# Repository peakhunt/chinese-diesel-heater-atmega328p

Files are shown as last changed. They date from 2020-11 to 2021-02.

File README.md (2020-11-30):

# DANGEROUS
please don't use it if you don't know what you are doing.  
this is still a work in progress and I'm just using it  
as an emergency for my personal heating in my workshop  
so that I can have a warm winter at least.  
  
some documents will be posted here later for those brave souls interested in this.

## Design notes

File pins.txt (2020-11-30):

LED                                                   Used
  PB5                                                 PB1,PB2,PB3,PB4,PB5
                                                      PC0,PC1,PC2,PC3,PC4,PC5
PWM                                                   PD0,PD1,PD2,PD3
  PB1
  PB2                                                 Availabl
                                                      PB0, PC6
GPIO Out
  PD2
  PD3
  PD4

GPIO In
  PD5
  PD6
  PD7

ADC
  PC0
  PC1
  PC2
  PC3

I2C
  PC4
  PC5

SPI
  PB3
  PB4
  PB5
  XXX - CS

UART
  PD0
  PD1

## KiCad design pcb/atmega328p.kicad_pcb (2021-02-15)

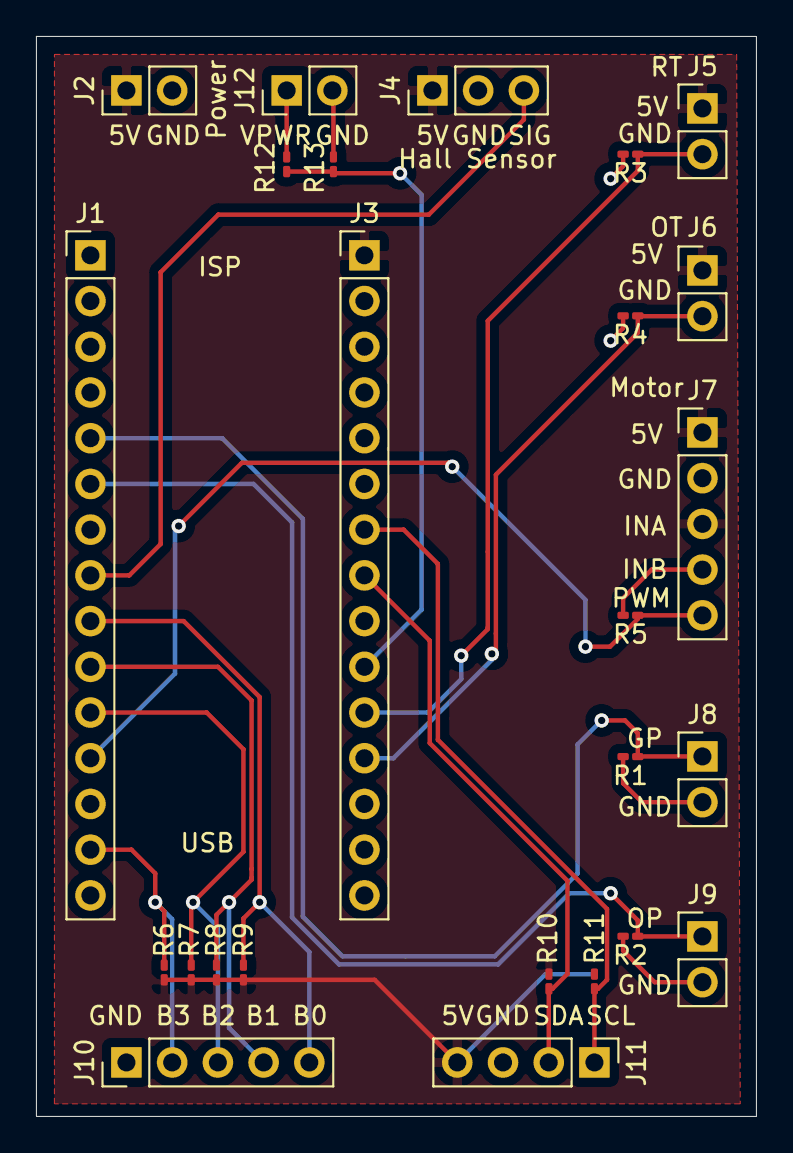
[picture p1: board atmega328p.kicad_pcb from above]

Board: 2 copper layers, 40.0 x 60.0 mm, 25 parts (0 on the bottom side), 16 nets.

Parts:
J1: Arduini MINI Left; PinHeader_1x15_P2.54mm_Vertical
J2, J12: Power; PinHeader_1x02_P2.54mm_Vertical
J3: Arduini MINI Right; PinHeader_1x15_P2.54mm_Vertical
J4: Hall Sensor; PinHeader_1x03_P2.54mm_Vertical
J5: Room Temperature; PinHeader_1x02_P2.54mm_Vertical
J6: Outlet Temperature; PinHeader_1x02_P2.54mm_Vertical
J7: Motor; PinHeader_1x05_P2.54mm_Vertical
J8: Glow Plug; PinHeader_1x02_P2.54mm_Vertical
J9: Oil Pump; PinHeader_1x02_P2.54mm_Vertical
J10: Buttons; PinHeader_1x05_P2.54mm_Vertical
J11: I2C; PinHeader_1x04_P2.54mm_Vertical
R1, R2, R5, R6, R7, R8, R9: 2K; R_0201_0603Metric_Pad0.64x0.40mm_HandSolder
R3, R4: 51K; R_0201_0603Metric_Pad0.64x0.40mm_HandSolder
R10, R11: 1K; R_0201_0603Metric_Pad0.64x0.40mm_HandSolder
R12: 6.8K; R_0201_0603Metric_Pad0.64x0.40mm_HandSolder
R13: 3.3K; R_0201_0603Metric_Pad0.64x0.40mm_HandSolder

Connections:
/5V: J2.1, J3.1, J4.1, J5.1, J6.1, J7.1, J7.3, J11.4, R6.2, R7.2, R8.2, R9.2, R10.1, R11.1
/12V: J12.1, R12.1
/BTN0: J1.9, J10.5, R9.1
/BTN1: J1.10, J10.4, R8.1
/BTN2: J1.11, J10.3, R7.1
/BTN3: J1.14, J10.2, R6.1
/GP_SIG: J1.5, J8.1, R1.1
/HS_INPUT: J1.8, J4.3
/M_PWM: J1.12, J7.5, R5.1
/OP_SIG: J1.6, J9.1, R2.1
/OT: J3.12, J6.2, R4.1
/RT: J3.11, J5.2, R3.1
/SCL: J3.7, J11.1, R11.2
/SDA: J3.8, J11.2, R10.2
/VPWR: J3.10, R12.2, R13.1
GND: J2.2, J3.2, J4.2, J7.2, J7.4, J8.2, J9.2, J10.1, J11.3, J12.2, R1.2, R2.2, R3.2, R4.2, R5.2, R13.2

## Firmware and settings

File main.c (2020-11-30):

#include <avr/io.h>
#include <avr/interrupt.h>

#include "mainloop_timer.h"
#include "event_dispatcher.h"
#include "sys_timer.h"
#include "misc.h"
#include "shell.h"
#include "pwm.h"
#include "gpio.h"
#include "adc_reader.h"

#include "heater.h"

int
main(void)
{
  // just to make sure, disable interrupt
  cli();

  event_dispatcher_init();
  mainloop_timer_init();

  pwm_init();
  gpio_init();
  misc_init();
  shell_init();
  sys_timer_init();

  adc_reader_init();

  heater_init();

  sei();

  shell_start();

  while(1)
  {
    event_dispatcher_dispatch();
  }
  return 0;
}

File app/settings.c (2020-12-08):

#include <avr/eeprom.h>
#include "settings.h"
#include "heater.h"
#include "glow_plug.h"
#include "oil_pump.h"

#define SETTINGS_MAGIC          0x1122334f
#define SETTINGS_EEPROM_ADDRESS 128

static settings_t   _settings;

void
settings_init(void)
{
  eeprom_read_block((void*)&_settings, (const void*)SETTINGS_EEPROM_ADDRESS, sizeof(settings_t));

  if(_settings.magic != SETTINGS_MAGIC)
  {
    // invalid settings
    // reset everything to default
    settings_reset();
  }
}

void
settings_reset(void)
{
  _settings.magic                             = SETTINGS_MAGIC;
  _settings.glow_plug_on_duration_for_start   = HEATER_HEATING_GLOW_PLUG_BEFORE_OIL_PUMP_PRIMING;
  _settings.oil_pump_priming_duration         = HEATER_OIL_PUMP_PRIMING_BEFORE_GLOW_PLUG_TURN_OFF;
  _settings.glow_plug_on_duration_for_stop    = HEATER_HEATING_GLOW_PLUG_BEFORE_COOLING_DOWN;
  _settings.cooling_down_period               = HEATER_COOLING_DOWN_AFTER_GLOW_PLUG_TURN_OFF;

  _settings.startup_fan_power                 = HEATER_STARTUP_FAN_POWER;
  _settings.stop_fan_power                    = HEATER_STOP_FAN_POWER;

  _settings.glow_plug_pwm_freq                = GLOW_PLUG_PWM_FREQ;
  _settings.glow_plug_pwm_duty                = GLOW_PLUG_PWM_DUTY;

  _settings.oil_pump_startup_freq             = OIL_PUMP_DEF_FREQ;
  _settings.oil_pump_pulse_length             = OIL_PUMP_PULSE_LENGTH;

  // optimal settings I found after some experiment
  _settings.steps[0].pump_freq  = 1.0f;
  _settings.steps[0].fan_pwr    = 45;

  _settings.steps[1].pump_freq  = 1.8f;
  _settings.steps[1].fan_pwr    = 50;

  _settings.steps[2].pump_freq  = 2.5f;
  _settings.steps[2].fan_pwr    = 60;

  _settings.steps[3].pump_freq  = 3.5f;
  _settings.steps[3].fan_pwr    = 70;

  _settings.steps[4].pump_freq  = 4.5f;
  _settings.steps[4].fan_pwr    = 75;

  settings_update();
}

void
settings_update(void)
{
  eeprom_update_block((void*)&_settings, (void*)SETTINGS_EEPROM_ADDRESS, sizeof(settings_t));
}

settings_t*
settings_get(void)
{
  return &_settings;
}

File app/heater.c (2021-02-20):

#include "heater.h"
#include "gpio.h"
#include "pwm.h"
#include "mainloop_timer.h"
#include "settings.h"

////////////////////////////////////////////////////////////////////////////////
//
// internals
//
////////////////////////////////////////////////////////////////////////////////
typedef enum
{
  heater_event_start_request = 0,
  heater_event_stop_request,
  heater_event_heating_glow_plug_complete_for_start,
  heater_event_oil_pump_priming_complete,
  heater_event_heating_glow_plug_complete_for_stop,
  heater_event_cooling_down_complete,
} heater_event_t;

static void heater_event(heater_event_t ev);

static heater_t         _heater;
static SoftTimerElem    _tmr;

////////////////////////////////////////////////////////////////////////////////
//
// heater state machine
//
////////////////////////////////////////////////////////////////////////////////
static void
heater_change_state(heater_state_t ns)
{
  _heater.state = ns;
}

static void
heater_timer_callback(SoftTimerElem* te)
{
  switch(_heater.state)
  {
  case heater_state_heating_glow_plug_for_start:
    heater_event(heater_event_heating_glow_plug_complete_for_start);
    break;

  case heater_state_oil_pump_priming:
    heater_event(heater_event_oil_pump_priming_complete);
    break;

  case heater_state_heating_glow_plug_for_stop:
    heater_event(heater_event_heating_glow_plug_complete_for_stop);
    break;

  case heater_state_cooling_down:
    heater_event(heater_event_cooling_down_complete);
    break;

  default:
    break;
  }
}

static void
handle_heater_event_state_off(heater_event_t ev)
{
  switch(ev)
  {
  case heater_event_start_request:
    fan_start(&_heater.fan);
    fan_set_power(&_heater.fan, settings_get()->startup_fan_power);
    glow_plug_on(&_heater.glow_plug);

    mainloop_timer_schedule(&_tmr, settings_get()->glow_plug_on_duration_for_start);

    heater_change_state(heater_state_heating_glow_plug_for_start);
    break;

  default:
    break;
  }
}

static void
handle_heater_event_state_heating_glow_plug_for_start(heater_event_t ev)
{
  switch(ev)
  {
  case heater_event_heating_glow_plug_complete_for_start:
    oil_pump_on(&_heater.oil_pump);
    oil_pump_change_freq(&_heater.oil_pump,
        settings_get()->oil_pump_startup_freq);

    mainloop_timer_schedule(&_tmr, settings_get()->oil_pump_priming_duration);

    heater_change_state(heater_state_oil_pump_priming);
    break;

  default:
    break;
  }
}

static void
handle_heater_event_state_oil_pump_priming(heater_event_t ev)
{
  switch(ev)
  {
  case heater_event_oil_pump_priming_complete:
    glow_plug_off(&_heater.glow_plug);

    heater_set_step(0);

    heater_change_state(heater_state_running);
    break;

  default:
    break;
  }
}

static void
handle_heater_event_state_running(heater_event_t ev)
{
  switch(ev)
  {
  case heater_event_stop_request:
    fan_set_power(&_heater.fan, settings_get()->stop_fan_power);
    oil_pump_off(&_heater.oil_pump);
    glow_plug_on(&_heater.glow_plug);

    mainloop_timer_schedule(&_tmr, settings_get()->glow_plug_on_duration_for_stop);

    heater_change_state(heater_state_heating_glow_plug_for_stop);
    break;

  default:
    break;
  }
}

static void
handle_heater_event_state_heating_glow_plug_for_stop(heater_event_t ev)
{
  switch(ev)
  {
  case heater_event_heating_glow_plug_complete_for_stop:
    glow_plug_off(&_heater.glow_plug);

    mainloop_timer_schedule(&_tmr, settings_get()->cooling_down_period);

    heater_change_state(heater_state_cooling_down);
    break;

  default:
    break;
  }
}

static void
handle_heater_event_state_cooling_down(heater_event_t ev)
{
  switch(ev)
  {
  case heater_event_cooling_down_complete:
    fan_stop(&_heater.fan);

    heater_change_state(heater_state_off);
    break;

  default:
    break;
  }
}

static void
heater_event(heater_event_t ev)
{
  switch(_heater.state)
  {
  case heater_state_off:
    handle_heater_event_state_off(ev);
    break;

  case heater_state_heating_glow_plug_for_start:
    handle_heater_event_state_heating_glow_plug_for_start(ev);
    break;

  case heater_state_oil_pump_priming:
    handle_heater_event_state_oil_pump_priming(ev);
    break;

  case heater_state_running:
    handle_heater_event_state_running(ev);
    break;

  case heater_state_heating_glow_plug_for_stop:
    handle_heater_event_state_heating_glow_plug_for_stop(ev);
    break;

  case heater_state_cooling_down:
    handle_heater_event_state_cooling_down(ev);
    break;
  }
}

////////////////////////////////////////////////////////////////////////////////
//
// heater state machine
//
////////////////////////////////////////////////////////////////////////////////
void
heater_init(void)
{
  settings_init();

  _heater.state = heater_state_off;
  _heater.step  = 0;

  glow_plug_init(&_heater.glow_plug, gpio_out_pin_pd2);
  oil_pump_init(&_heater.oil_pump, gpio_out_pin_pd3);
  fan_init(&_heater.fan, pwm_channel_0, gpio_in_pin_pd5);

  //
  // 5V source. 51K R2 in voltage divider circuit
  //
  ntc50_init(&_heater.outlet_temp, 5, 51 * 1000.0f, adc_channel_0);
  ntc50_init(&_heater.room_temp, 5, 51 * 1000.0f, adc_channel_1);

  soft_timer_init_elem(&_tmr);
  _tmr.cb = heater_timer_callback;
}

void
heater_start(void)
{
  heater_event(heater_event_start_request);
}

void
heater_stop(void)
{
  heater_event(heater_event_stop_request);
}

const heater_t*
heater_get(void)
{
  return &_heater;
}

void
heater_glow_plug_on(void)
{
  glow_plug_on(&_heater.glow_plug);
}

void
heater_glow_plug_off(void)
{
  glow_plug_off(&_heater.glow_plug);
}

void
heater_oil_pump_on(void)
{
  oil_pump_on(&_heater.oil_pump);
}

void
heater_oil_pump_off(void)
{
  oil_pump_off(&_heater.oil_pump);
}

void
heater_oil_pump_freq(float freq)
{
  oil_pump_change_freq(&_heater.oil_pump, freq);
}

void
heater_fan_on(void)
{
  fan_start(&_heater.fan);
}

void
heater_fan_off(void)
{
  fan_stop(&_heater.fan);
}

void
heater_set_step(uint8_t step)
{
  fan_set_power(&_heater.fan, settings_get()->steps[step].fan_pwr);
  oil_pump_change_freq(&_heater.oil_pump, settings_get()->steps[step].pump_freq);
  _heater.step = step;
}

void
heater_fan_power(uint8_t pwr)
{
  fan_set_power(&_heater.fan, pwr);
}

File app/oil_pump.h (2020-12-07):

#ifndef __OIL_PUMP_DEF_H__
#define __OIL_PUMP_DEF_H__

#include "app_common.h"
#include "gpio.h"
#include "soft_pwm.h"

#define OIL_PUMP_DEF_FREQ     1.8f      // 1.8Hz
#define OIL_PUMP_PULSE_LENGTH 50        // 50ms

#define OIL_PUMP_MIN_FREQ     0.8f
#define OIL_PUMP_MAX_FREQ     5.0f

typedef struct
{
  bool        on;
  float       freq;
  soft_pwm_t  pwm;
} oil_pump_t;

extern void oil_pump_init(oil_pump_t* op, gpio_out_pin_t pin);
extern void oil_pump_on(oil_pump_t* op);
extern void oil_pump_off(oil_pump_t* op);
extern void oil_pump_change_freq(oil_pump_t* op, float freq);

#endif /* !__OIL_PUMP_DEF_H__ */

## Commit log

2020-12-01 changed oil pump min/max frequency. this could burn the heater if fan is malfunctioning
    [oil_pump.h]
2020-12-01 a bunch of string optimization macros to reduce sram usage. Soon I will move to stm32 for a new development
2020-12-07 adding ntc50k support for outlet temperature measurement. the result is highly inaccurate but it can be used for flame detection at least
2020-12-08 changed ntc50 data gathering mechanism. now it is synchronized with adc. added a simple low pass filter
2020-12-08 added option not to use debouncer and switched to callback mechanism primarily to interface with hall sensor to detect if motor is running
2020-12-08 added some comments about interrupt enable/disable not to forget
2020-12-08 added experimental motor running detection code
2020-12-11 fixed a buf of not setting oil pump startup frequency when starting
    [heater.c]
2021-02-15 adding pcb
    [atmega328p-B_Cu.gbr, atmega328p-B_Mask.gbr, atmega328p-B_Paste.gbr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]
2021-02-15 added batter power adc
    [atmega328p-B_Cu.gbr, atmega328p-B_Mask.gbr, atmega328p-B_Paste.gbr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]
2021-02-20 added ntc50k for room temperature
